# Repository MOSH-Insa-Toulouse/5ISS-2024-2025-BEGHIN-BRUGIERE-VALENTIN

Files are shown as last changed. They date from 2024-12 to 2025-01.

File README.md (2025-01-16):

# Gaz Sensor Application

## Introduction
The general objective of this project is to carry out the complete implementation of a gas sensor, from its manufacture, through its integration on a PCB, to its use in a concrete IoT application. This course gives us the opportunity to put our skills into practice at every stage in the design and development of a project. In particular, it covers the main phases such as hardware design, software design and product integration. Various digital tools were used, including KiCad for PCB design, LTSpice for analogue simulations and the Arduino platform for programming.

The application developed detects carbon monoxide and alerts you if critical thresholds are exceeded. Three LEDs indicate the alert levels: green for a safe level, orange for a high level and red for a dangerous level requiring evacuation. An OLED screen, connected via I2C, displays CO levels in real time to check the accuracy of the measurements. These measurements are then sent via a LoRa antenna and retrieved using the NodeRed software, which displays them.

This Git file and the following document contain the steps required to design our application, as well as the results obtained.

## LoRa Antenna
As mentioned above, the aim is to send the data measured by the sensor via a LoRa antenna. To do this, we used the open-source LoRaWAN Network Server ChirpStack, on which we created our application and generated its identifier and access key. Via this server, it is possible to connect to the GEI's main LoRa antenna and view the data stream sent to it.

On the programming side, we used the LoRa RN2483. This module has the advantage of communicating via the UART, so it was easy to connect it to the Arduino and have it send and receive data. We then had to reset and configure the RN2483 microchip according to the identifiers created on ChirpStack. Once this was done, we launched the connection tests and were able to check that our antenna was indeed connected to the main antenna via ChirpStack.

## Components Integration
### OLED Screen
As already mentioned, the OLED screen displays the carbon monoxide level measured by the sensor. The display is of the SSD1306 type and communicates via the I2C bus. We were therefore able to integrate it easily into our system, in particular by using adafruit libraries. By configuring the screen display, i.e. the size, colour and position of the text, we were able to display our first tests on the screen. We also used this screen as a test indicator to check the veracity and accuracy of the measurements taken by the sensor.
### Gaz Sensor
Adding the gas sensor to the application was not so easy. We had trouble understanding how the sensor worked and how to retrieve the measurements. However, after a bit of research we managed to get it to work properly.

This sensor detects the presence of carbon monoxide by a variation in resistance. First of all, the sensor has to be allowed to heat up in order to obtain values in line with reality, and then to adapt to its environment. The resistance value is recovered via a serial link and processed to obtain a usable level in ppm. We were then able to display on the screen the measurements taken in real time by the sensor.
### LEDs
To implement a visual alert, we decided to use three different coloured LEDs to symbolise our alert levels. The first level, green, means that the level of CO measured by the sensor is not toxic. The second, orange, symbolises that the quantity of gas is high and that exposure for too long can cause headaches. Finally, the red alert level lights up when the level of monoxide is above the safety threshold. Time to leave the room. We found the three thresholds in the literature on the websites of health bodies to reflect reality. The LEDs were switched on via a condition loop when the sensor measurements were retrieved.

## Node-RED Application
After that, we implemented Node-RED to visualise the data collected by the sensor. The idea was for the sensor readings transmitted via the LoRa antenna and processed by Chirpstack to be retrieved by Node-RED and displayed using its dashboard functionality. Using the MQTT protocol, we subscribed Node-RED to a Chirpstack topic in which it published the sensor measurements. This enabled us to retrieve the data transmitted on the LoRa network. The values were then displayed by creating a simple but powerful interface for viewing the gas sensor data in real time. 

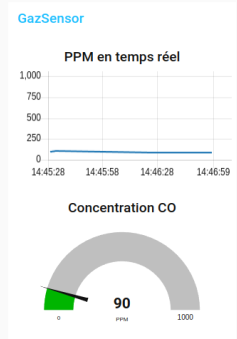
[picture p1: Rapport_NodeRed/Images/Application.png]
Node-Red Dashboard Vizualisation Node-Red Dashboard Vizualisation


For more information, read the Node-RED report [here](Rapport_NodeRed).

## The electrical circuit
Here is the complete electrical diagram of our system. It consists of the Arduino UNO shield, the three LEDs, the gas sensor, the OLED screen and an amplifier.

Electrical Circuit

The gas sensor produced has a very high resistance which varies according to the type and presence of gas. Its resistance is of the order of gigohms, which implies an extremely low current of the order of nanoampere (nA) flowing to the ADC. Using an Arduino with a 10-bit ADC requires the signal leaving the gas sensor to be amplified. We therefore designed an amplification circuit based on an operational amplifier and simulated it using LTSpice. To find out more, read the LT-Spice report [here](Rapport_LTSpice).

Amplifier

## PCB Design
The PCB was designed using KiCad software. Starting with the previous electrical circuit, the components had to be placed on the Arduino UNO shield and then routed. This was a complex process because we had a lot of components that were quite imposing in terms of space, which did not make placement easy. The final aim was, instead of using a breadboard, to have all the components needed for our application on a single board. The OLED screen and the connectors for the LoRa module have been placed on the other side of the shield so that they can be accessed. Here is the final PCB for our project.

PCB Design

Below, there is a 3D view of the PCB after conception.

-- Front view:

3D view front

--Back view:

3D view back

## Conclusion
The next stage of our project is to print the PCB and then solder the components. Finally, we will have to test our application by uploading our code onto the board. 

The overall objective of this module is to carry out the complete implementation of a gas sensor, from its manufacture, through its integration on a PCB, to its use in a concrete IoT application. This course thus gives us the opportunity to put our skills into practice at every stage of the design and development of a project. In particular, it covers the main phases such as hardware design, software design and product integration. 

In terms of energy consumption, we should look at the consumption of each component. If it is too high, we will have to switch to other components that consume less energy.

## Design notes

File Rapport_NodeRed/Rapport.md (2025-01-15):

# Node-RED in the Gas Sensor Monitoring Project

## Introduction

As part of our project, we implemented Node-RED to visualize data collected by a gas sensor. The sensor readings, transmitted via LoRa and processed by Chirpstack, were retrieved in Node-RED and displayed using its dashboard capabilities. This document outlines how we configured Node-RED for real-time data visualization.

---

## Role of Node-RED in Our Project

In our project, we used Node-RED for the visualization of gas sensor data. Its role was focused on:

1. **Data Retrieval**: Using an MQTT node, Node-RED subscribed to a Chirpstack topic to receive the sensor data transmitted over the LoRa network.
2. **Data Visualization**: The `node-red-dashboard` package allowed us to create a user interface for real-time monitoring of the gas concentration, specifically CO levels.

---

## Configuration of Node-RED for Data Visualization

To integrate Node-RED into our workflow, we followed the steps below:

### 1. Connecting to Chirpstack via MQTT
We used the `mqtt in` node to subscribe to the topic where Chirpstack published the gas sensor data. The node was configured with the following:
- The broker URL and port of Chirpstack.
- The correct topic for sensor data.
- Authentication details where required.

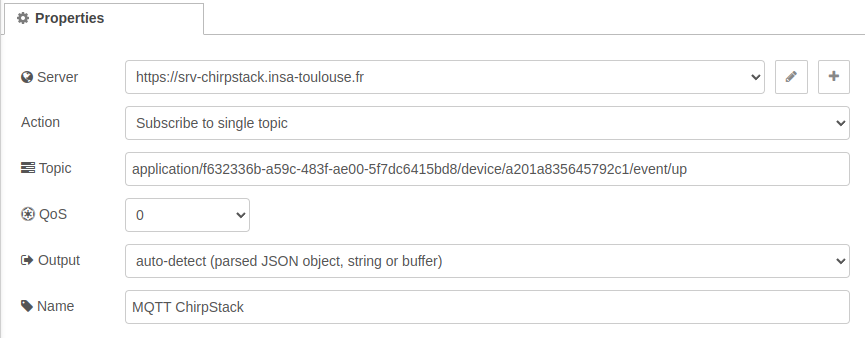
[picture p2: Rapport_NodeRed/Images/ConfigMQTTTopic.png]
Configuration Topic Broker MQTT

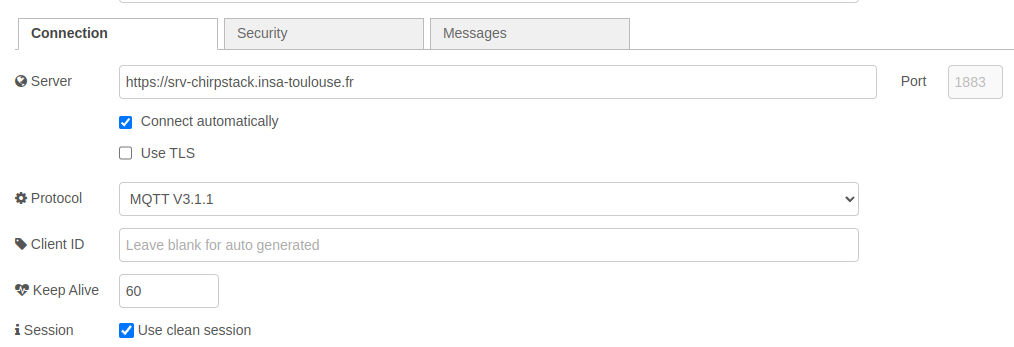
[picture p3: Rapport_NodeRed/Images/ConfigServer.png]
Configuration Server MQTT


### 2. Parsing the Data
The raw payload received from the MQTT node was in JSON format. We processed this data as follows:
- A `JSON` node was used to parse the payload into a structured format for easy handling.
- Function nodes were added to extract specific details such as gas concentration values and to reformat the data for better compatibility with dashboard widgets.

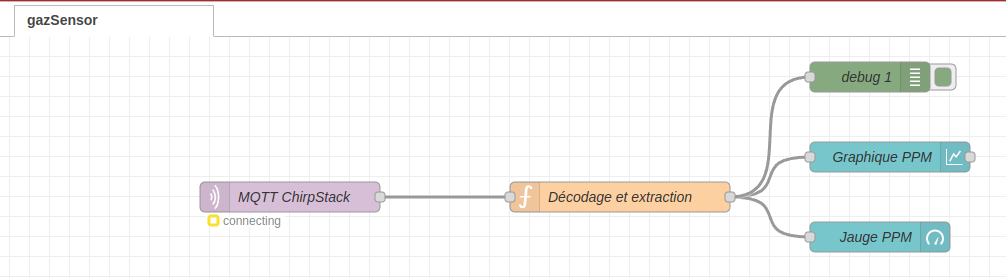
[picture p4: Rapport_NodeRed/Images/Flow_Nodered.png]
Node-Red Flow


### 3. Dashboard Configuration
For the visualization, we installed and configured the `node-red-dashboard` package:
- **Gauges** were used to display the current gas concentration levels.
- **Charts** plotted historical trends of gas readings over time.

Node-Red Dashboard Vizualisation Node-Red Dashboard Vizualisation

---

## Node-RED Flow Overview

Our Node-RED flow consisted of the following key components:

1. **Input Node**:
   - `mqtt in`: Subscribed to the Chirpstack topic for gas sensor data.
2. **Processing Node**:
   - `json`: Converted the raw payload into structured data.
3. **Visualization Nodes**:
   - `ui_gauge`: Displayed the current gas concentration level.
   - `ui_chart`: Graphed the real-time trends of gas readings.
   - `ui_text`: Added labels and contextual information.

*Image suggestion*: Provide a screenshot of the complete flow diagram from Node-RED to help visualize the workflow.

---

## Conclusion

Through Node-RED, we successfully created a simple yet powerful interface for visualizing gas sensor data in real time. The combination of MQTT integration and interactive dashboard widgets enabled us to effectively monitor CO levels transmitted via the LoRa network. This experience highlighted Node-RED’s suitability for rapid prototyping and student projects like ours, where simplicity and efficiency are key.

---

*Image suggestion*: Include a final screenshot of the dashboard showing live sensor data to showcase the outcome of the project.

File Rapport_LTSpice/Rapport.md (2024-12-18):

# Amplification Circuit for Gas Sensor with LTSpice Simulation

## Overview

The gas sensor made during the AIME week internship has an extremely high resistance that varies depending on the type and presence of gas. Its resistance is on the order of **gigohms**, resulting in an extremely low current in the **nanoampere (nA)** range flowing to the ADC. Using an Arduino with a 10-bit ADC necessitates amplifying the signal exiting the gas sensor. We designed an amplifier circuit based on an operational amplifier and simulated it using LTSpice.

Amplifying the signal allows us to avoid the need for expensive equipment like a €15,000 multimeter to measure the high resistance.

---

## Amplifying the Signal from the Sensor

### LTSpice Simulation

The amplifier uses **three different filters**, each with its own cutoff frequency. These filters are essential for shaping the signal and reducing noise. To accurately simulate the gas sensor's behavior, we created a custom sensor component in LTSpice that mimics its high resistance and response to gases.

### Circuit for Simulating the Sensor

Below is the LTSpice circuit used to simulate the gas sensor:

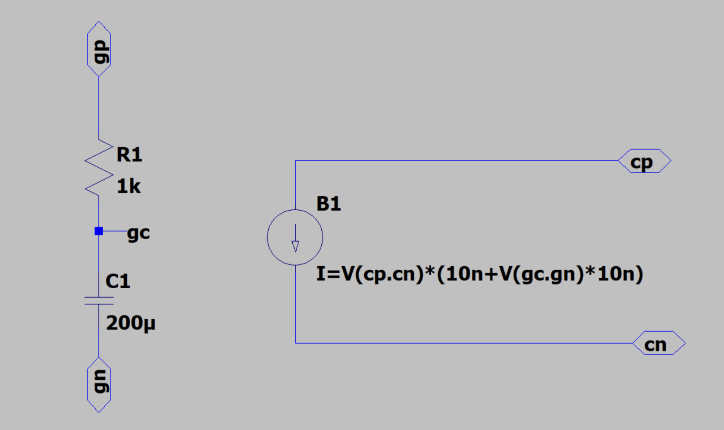
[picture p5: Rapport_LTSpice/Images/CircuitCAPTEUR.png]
Sensor Simulation Circuit


### LTSpice Circuit of the Amplifier

Below is the LTSpice circuit, integrating the gas sensor and filters:  
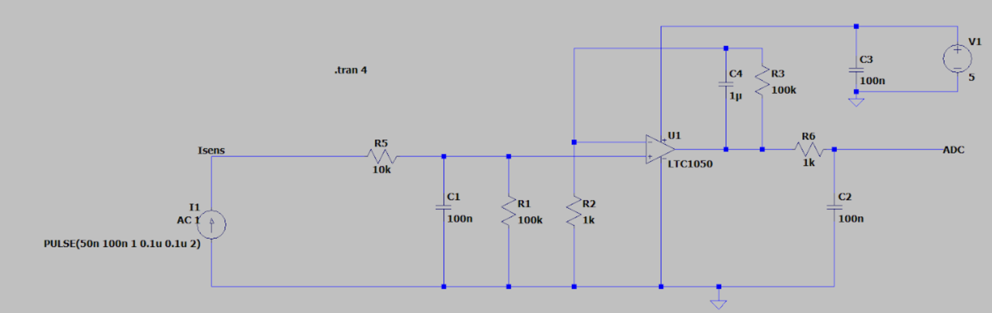
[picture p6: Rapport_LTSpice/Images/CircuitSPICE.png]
Sensor Simulation Circuit


---

## Verification of Nominal Functionality of the Amplifier

### Transient Response

Below is the LTSpice transient simulation for the input and output:

#### Input Transient Simulation:
- Input: PULSE of current, from **50 nA** to **100 nA**.
- Output observed: **5 mV** to **10 mV**, due to the **100 kΩ shunt resistance**.

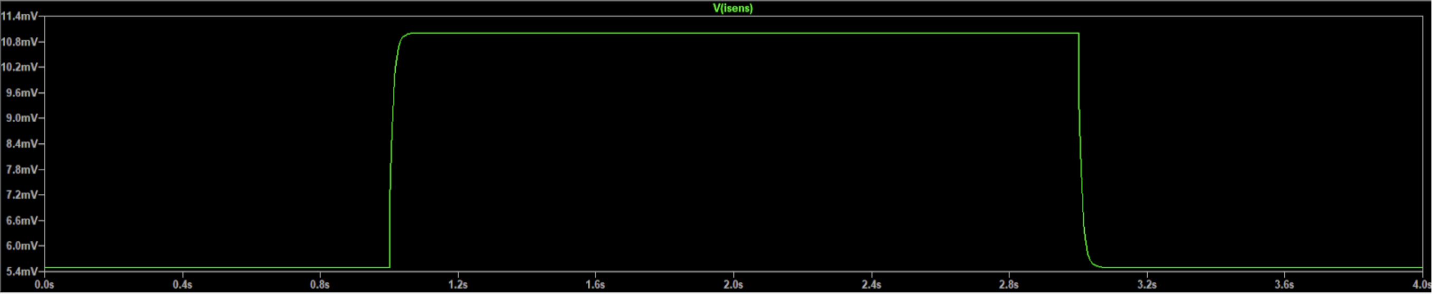
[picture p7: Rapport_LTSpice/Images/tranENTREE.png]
Transient Input


#### Output Transient Simulation:
- Voltage at the ADC is amplified by a factor of **101** (gain of the Amplificator = $1+\frac{100\text{k}}{1\text{k}}$).

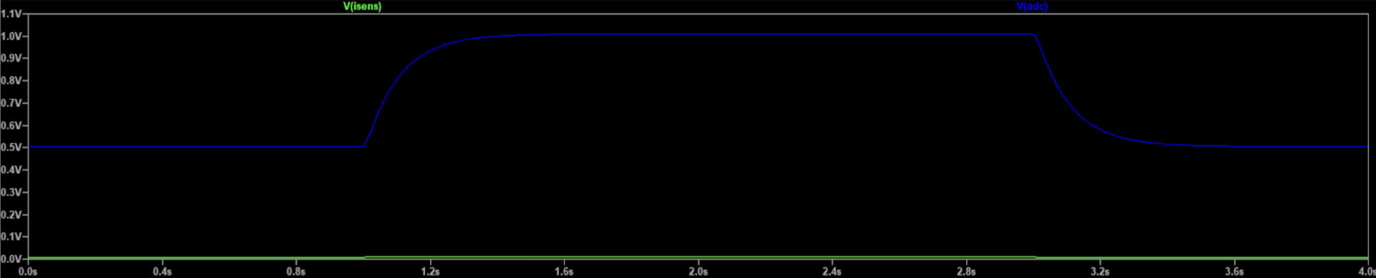
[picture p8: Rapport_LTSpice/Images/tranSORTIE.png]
Transient Output


The behaviour of our Amplifier is therefore correct, and we can go through the frequency analysis.

---

## Frequency Analysis

### Bode Diagram

The Bode diagram below shows the frequency response of the amplifier circuit:

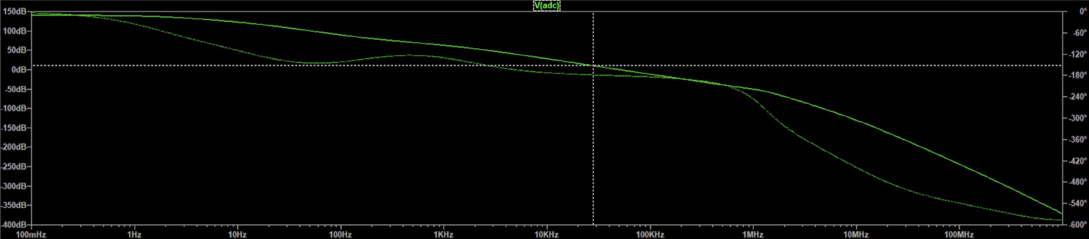
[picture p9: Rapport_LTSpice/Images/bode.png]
Bode Diagram Bode Diagram of Amplifier Circuit


The observed gain is **140 dB**, consistent with theoretical expectations.
Indeed, the transfer function is given by:

$H = \frac{V_{\text{out}}}{I_{\text{in}}}$

Where $V_{\text{out}} = 0.5 \text{V}$, $I_{\text{in}} = 50 \text{nA}$.  
Substituting into the formula, we get:

$H = \frac{0.5}{50 \times 10^{-9}} = 10^7$

On the other hand, we have 
$140 \text{dB}=10^{\frac{140}{20}} = 10^7$.
 
The Bode diagram results are coherent with the input-output data and confirm the amplifier's performance.

---

## Filter Design and Characterizing the Amplification

### Cutoff Frequencies and Attenuation

Below are the cutoff frequencies for each filter. They have been measured in LTSpice:

| Filter | Cutoff Frequency |
|---|---|
| 1 | $15$ Hz |
| 2 | $1.6$ Hz |
| 3 | $1.55$ kHz |

The filters have the following purposes:
1. **First Filter (C1, R1, R5):** Filters out noise originating from the gas sensor itself.
2. **Second Filter (C4, R3):** Reduces the **50 Hz** noise from the power grid.
3. **Third Filter (C2, R6):** Acts as an **anti-aliasing filter**, preventing signal distortion during digitization.

---

## Analysis of Noise and Filtering

### Frequency Analysis and Noise Reduction

FFT analysis of the ADC voltage demonstrates the effectiveness of the filters in reducing noise:
- **50 Hz Noise:** Clearly attenuated by the second filter (C4, R3).
- Increasing the second filter's capacitance reduces the 50 Hz noise further. However, excessive capacitance can distort the signal.

Fast Fourier Transform with the original filter:
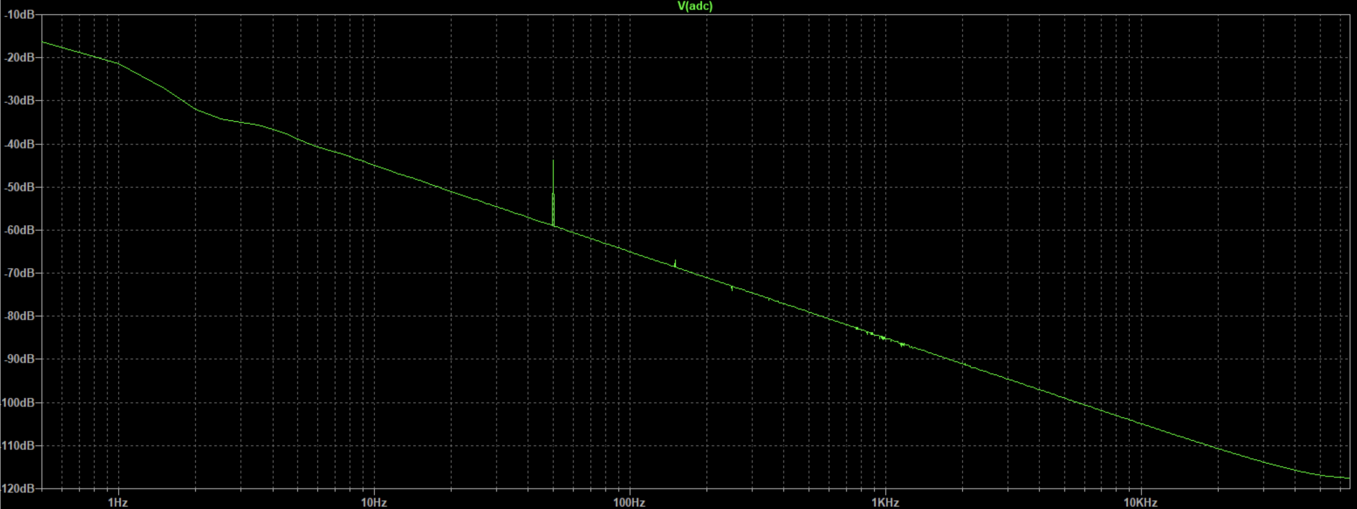
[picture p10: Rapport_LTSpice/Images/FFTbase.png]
FFT Bode Diagram of Amplifier Circuit


Fast Fourier Transform when increasing the capacitor too much:
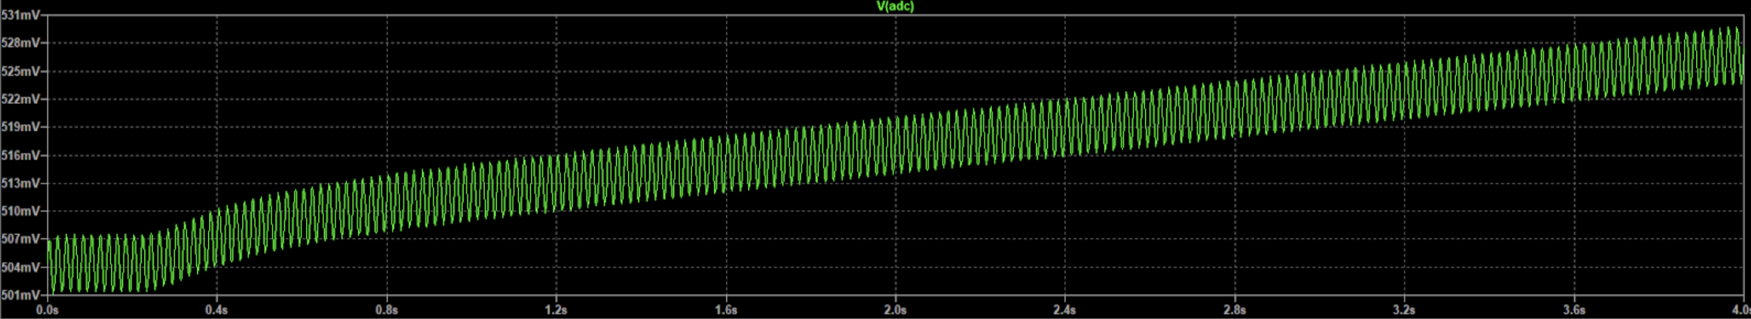
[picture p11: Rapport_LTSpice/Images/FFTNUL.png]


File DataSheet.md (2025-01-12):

# DataSheet of the gaz sensor

*This document presents the datasheet of the gaz sensor based on tungsten trioxide nanoparticles, manufactured at AIME.*

sensor 

**Main Features**             
  - Small size
  - Low cost                 
  - Detection of Ethanol ($C_2H_6O$)                              
  - Short response time
  - Integrated Temperature sensor

## Sensor Description
This gas sensor is designed to identify the presence of $C_2H_6O$ in the atmosphere. It functions as a passive component that detects gas presence through variations in its internal resistance. The incorporation of tungsten trioxide nanoparticles alters the conductivity of the aluminum interdigitated combs based on the gas composition in contact with the sensor. An internal heater allows the sensor to reach temperatures of up to 250°C, enhancing the sensitivity of the nanoparticles and minimizing interference from ambient humidity. Additionally, the sensor features an aluminum resistor to monitor its temperature, enabling improved control and the potential for temperature autoregulation.

## Pin Description
bottom_view 

| Pin Number | Usage |
|---|---|
| 1/6  |  Temperature sensor (Aluminium resistor) |
| 2/4  | Gas sensor ($WO_3$ nanoparticles integrated on aluminium interdigital combs) |
| 3/8  |  Heater resistor (Polysilicon resistor) |
| 7/9  |  Gas sensor ($WO_3$ nanoparticles integrated on aluminium interdigital combs) |
| 5/10  |  Not connected |

## Specifications
|  | Specificities |
|---|---|
| Type  | Nanoparticle based sensor |
| Sensor  | Passive (power supply required) |
| Materials  | - Silicon<br>- N-doped poly-silicon (heater)<br>- Aluminum (temperature measurement)<br>- Nanoparticles of tungsten trioxide ($WO_3$) |
| Detectable gaz  | Ethanol ($C_2H_6O$) |
| Gas measurement |  Resistance |
| Temperature measurement |  Resistance |
|  Package  | 10-Lead TO-5 metal  |
|  Diameter | 9.5 mm |

## Standard Test Conditions
|  | Unit | Typical Values |
|---|---|---|
| Temperature | °C | 20±5 |
| Humidity | % | 60±5 |
| Air quality | % $N_2/O_2$ | 80/20 |

## Electrical characteristics

<table>
  <tr>
    <th rowspan="2"></th>
    <th rowspan="2">Unit</th>
    <th colspan="3">Value</th>
  </tr>
  <tr>
    <th>Min</th>
    <th>Typical</th>
    <th>Max</th>
  </tr>
  <tr>
    <td>Gas sensor resistance</td>
    <td>GΩ</td>
    <td>-</td>
    <td>20</td>
    <td>-</td>
  </tr>
  <tr>
    <td>Temperature sensor resistance</td>
    <td>Ω</td>
    <td>84</td>
    <td>107.53</td>
    <td>108</td>
  </tr>
  <tr>
    <td>Heater resistance</td>
    <td>Ω</td>
    <td>70</td>
    <td>96.15</td>
    <td>98</td>
  </tr>
  <tr>
    <td>Gas sensor voltage</td>
    <td>V</td>
    <td>-</td>
    <td>5</td>
    <td>-</td>
  </tr>
  <tr>
    <td>Temperature sensor voltage</td>
    <td>V</td>
    <td>0</td>
    <td>5</td>
    <td>10</td>
  </tr>
  <tr>
    <td>Heater voltage</td>
    <td>V</td>
    <td>0</td>
    <td>10</td>
    <td>15</td>
  </tr>
</table>

## Temperature sensor characteristics
grapheALUAIME
From this graph representing the evolution of the temperature resistor, we obtain that the resistance is approximately : 107.53 Ω.

## Heating resistor characteristics


From this graph representing the evolution of the heater resistor, we obtain that the resistance is approximately : 96.15 Ω.

## Gas sensor characteristics
The gas sensor characteristic is determined by measuring the resistance evolution in presence of ethanol. When the resistance drops, the amount of ethanol in the environment increases. The gap is proportionnal to the gas concetration. 
gaz

## Sensor Integration

gazsensor

Above, there is a typical application of the sensor in an analogic circuit. The gaz sensor is 
connected in series with a resistors and with a RC filter. This filter aims to attenuate high frequencies. The outcoming tension is amplified 
by a LTC1050 operational amplifier before being filtered by a low pass filter. The 
tension from the ADC1 label can be connected to a 5V ADC such as an Arduino’s. 
The temperature sensor at pin TempB is also used as a resistor in a dividing bridge and the 
tension can be gathered by the ADC2 label. 

## Dimensions
The gas sensor uses a 10-Lead TO-5 metal package with the following dimensions:

dim

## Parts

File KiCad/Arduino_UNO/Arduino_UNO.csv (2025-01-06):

Source: | C:\Users\leabe\Documents\5A\MOSH\Arduino_UNO\Arduino_UNO.kicad_sch
Date: | 06/01/2025 14:32:44
Tool: | Eeschema 7.0.8
Generator: | C:\Program Files\KiCad\7.0\bin\scripting\plugins/bom_csv_grouped_by_value_with_fp.py
Component Count: | 25
Ref | Qnty | Value | Cmp name | Footprint | Description | Vendor | DNP
C1, C2, C3 | 3 | 100n | C | Capacitor_THT:C_Disc_D5.1mm_W3.2mm_P5.00mm | Unpolarized capacitor
C4 | 1 | 1u | C | Capacitor_THT:C_Rect_L7.5mm_W6.5mm_P5.00mm | Unpolarized capacitor
D1 | 1 | LED_Verte | LED | LED_THT:LED_D3.0mm | Light emitting diode
D2 | 1 | LED_Jaune | LED | LED_THT:LED_D3.0mm | Light emitting diode
D3 | 1 | LED_Rouge | LED | LED_THT:LED_D3.0mm | Light emitting diode
J1 | 1 | Power | Conn_01x08_1 | Connector_PinSocket_2.54mm:PinSocket_1x08_P2.54mm_Vertical | Generic connector, single row, 01x08, script generated (kicad-library-utils/schlib/autogen/connector/)
J2 | 1 | Digital/PWM | Conn_01x10 | Connector_PinSocket_2.54mm:PinSocket_1x10_P2.54mm_Vertical | Generic connector, single row, 01x10, script generated (kicad-library-utils/schlib/autogen/connector/)
J3 | 1 | Analog | Conn_01x06 | Connector_PinSocket_2.54mm:PinSocket_1x06_P2.54mm_Vertical | Generic connector, single row, 01x06, script generated (kicad-library-utils/schlib/autogen/connector/)
J4 | 1 | Digital/PWM | Conn_01x08 | Connector_PinSocket_2.54mm:PinSocket_1x08_P2.54mm_Vertical | Generic connector, single row, 01x08, script generated (kicad-library-utils/schlib/autogen/connector/)
J5 | 1 | Connecteur LoRa | Conn_01x08_2 | Connector_PinSocket_2.54mm:PinSocket_1x08_P2.54mm_Vertical | Generic connector, single row, 01x08, script generated (kicad-library-utils/schlib/autogen/connector/)
R1, R3 | 2 | 100k | R | Resistor_THT:R_Axial_DIN0207_L6.3mm_D2.5mm_P10.16mm_Horizontal | Resistor
R2, R6 | 2 | 1k | R | Resistor_THT:R_Axial_DIN0207_L6.3mm_D2.5mm_P10.16mm_Horizontal | Resistor
R4 | 1 | 100 | R | Resistor_THT:R_Axial_DIN0207_L6.3mm_D2.5mm_P10.16mm_Horizontal | Resistor
R5, R7 | 2 | 10k | R | Resistor_THT:R_Axial_DIN0207_L6.3mm_D2.5mm_P10.16mm_Horizontal | Resistor
R8, R9, R10 | 3 | 220 | R | Resistor_THT:R_Axial_DIN0207_L6.3mm_D2.5mm_P10.16mm_Horizontal | Resistor
U1 | 1 | LTC1050ACN8_PBF | LTC1050ACN8_PBF | Package_DIP:DIP-8_W7.62mm
U2 | 1 | DM-OLED096-636 | DM-OLED096-636 | DM-OLED096-636:MODULE_DM-OLED096-636
U3 | 1 | Gaz_Sensor | Gaz_Sensor | Package_TO_SOT_THT:TO-5-10_Window

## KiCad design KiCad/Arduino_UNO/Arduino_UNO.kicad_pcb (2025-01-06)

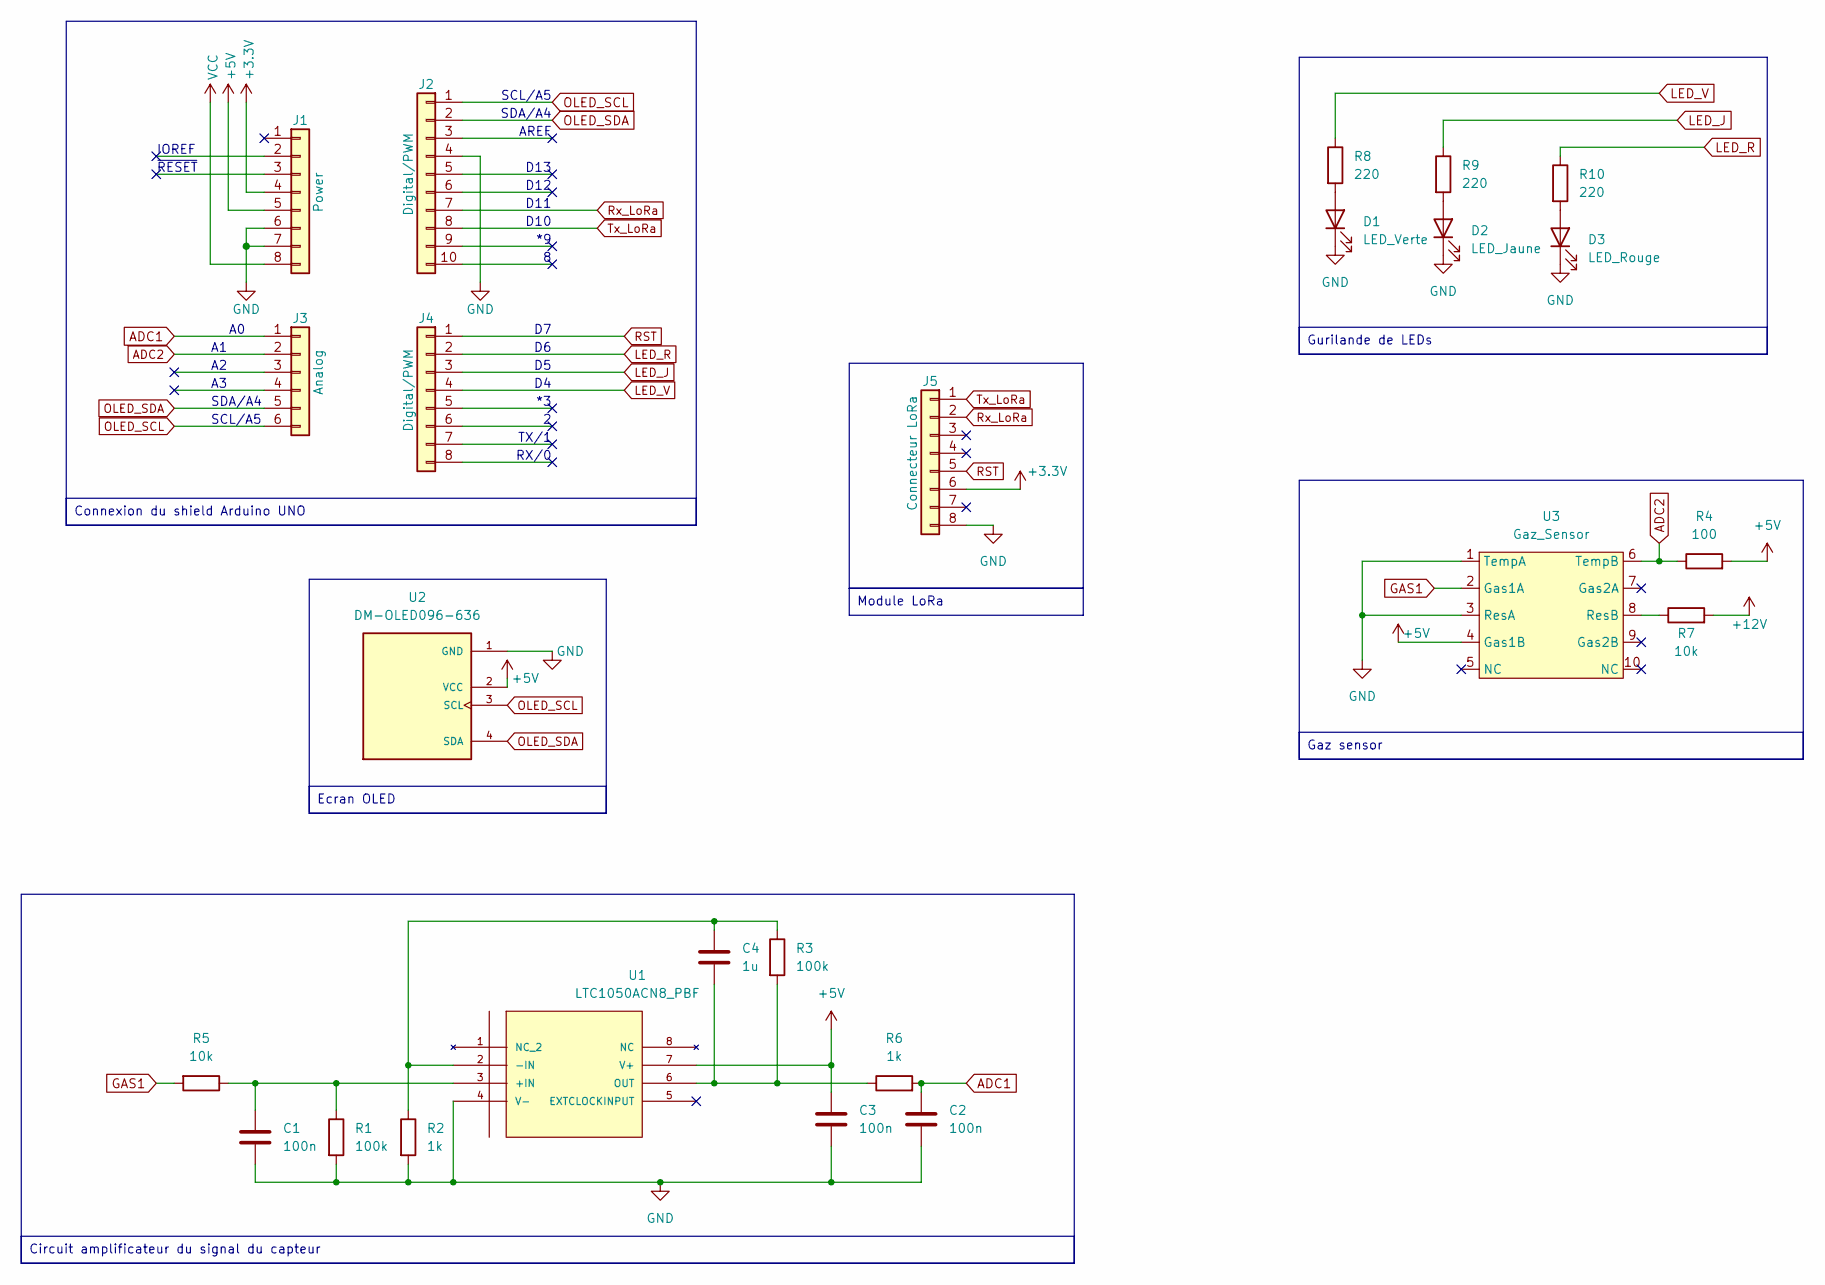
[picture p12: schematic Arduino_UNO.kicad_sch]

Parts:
C1, C2, C3: 100n; C_Disc_D5.1mm_W3.2mm_P5.00mm
C4: 1u; C_Rect_L7.5mm_W6.5mm_P5.00mm
D1: LED_Verte; LED_D3.0mm
D2: LED_Jaune; LED_D3.0mm
D3: LED_Rouge; LED_D3.0mm
J1: Power; PinSocket_1x08_P2.54mm_Vertical
J2: Digital/PWM; PinSocket_1x10_P2.54mm_Vertical
J3: Analog; PinSocket_1x06_P2.54mm_Vertical
J4: Digital/PWM; PinSocket_1x08_P2.54mm_Vertical
J5: Connecteur LoRa; PinSocket_1x08_P2.54mm_Vertical
R1, R3: 100k; R_Axial_DIN0207_L6.3mm_D2.5mm_P10.16mm_Horizontal
R2, R6: 1k; R_Axial_DIN0207_L6.3mm_D2.5mm_P10.16mm_Horizontal
R4: 100; R_Axial_DIN0207_L6.3mm_D2.5mm_P10.16mm_Horizontal
R5, R7: 10k; R_Axial_DIN0207_L6.3mm_D2.5mm_P10.16mm_Horizontal
R8, R9, R10: 220; R_Axial_DIN0207_L6.3mm_D2.5mm_P10.16mm_Horizontal
U1: LTC1050ACN8_PBF; DIP-8_W7.62mm; MANUFACTURER_PART_NUMBER ltc1050acn8
U2: DM-OLED096-636; MODULE_DM-OLED096-636; PARTREV 2018-09-10
U3: Gaz_Sensor; TO-5-10_Window

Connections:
+5V: C3.1, J1.5, R4.2, U1.7 (V+), U2.2 (VCC), U3.4 (Gas1B)
+12V: R7.2
ADC1: C2.1, J3.1, R6.2
ADC2: J3.2, R4.1, U3.6 (TempB)
GAS1: R5.2, U3.2 (Gas1A)
GND: C1.2, C2.2, C3.2, D1.1 (K), D2.1 (K), D3.1 (K), J1.6, J1.7, J2.4, J5.8, R1.2, R2.2, U1.4 (V-), U2.1 (GND), U3.1 (TempA), U3.3 (ResA)
LED_J: J4.3, R9.1
LED_R: J4.2, R10.1
LED_V: J4.4, R8.1
unnamed: D1.2 (A), R8.2
unnamed: D2.2 (A), R9.2
unnamed: D3.2 (A), R10.2
unnamed: C1.1, R1.1, R5.1, U1.3 (+IN)
unnamed: C4.1, R2.1, R3.1, U1.2 (-IN)
unnamed: C4.2, R3.2, R6.1, U1.6 (OUT)
unnamed: R7.1, U3.8 (ResB)
OLED_SCL: J2.1, J3.6, U2.3 (SCL)
OLED_SDA: J2.2, J3.5, U2.4 (SDA)
RST: J4.1, J5.5
Rx_LoRa: J2.7, J5.2
Tx_LoRa: J2.8, J5.1
VCC: J1.8

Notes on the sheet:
Gaz sensor
Gurilande de LEDs
Connexion du shield Arduino UNO
Module LoRa
Circuit amplificateur du signal du capteur
Ecran OLED
AREF
SCL/A5
TX/1
D13
~{RESET}
D12
D10
SDA/A4
RX/0
IOREF
D11

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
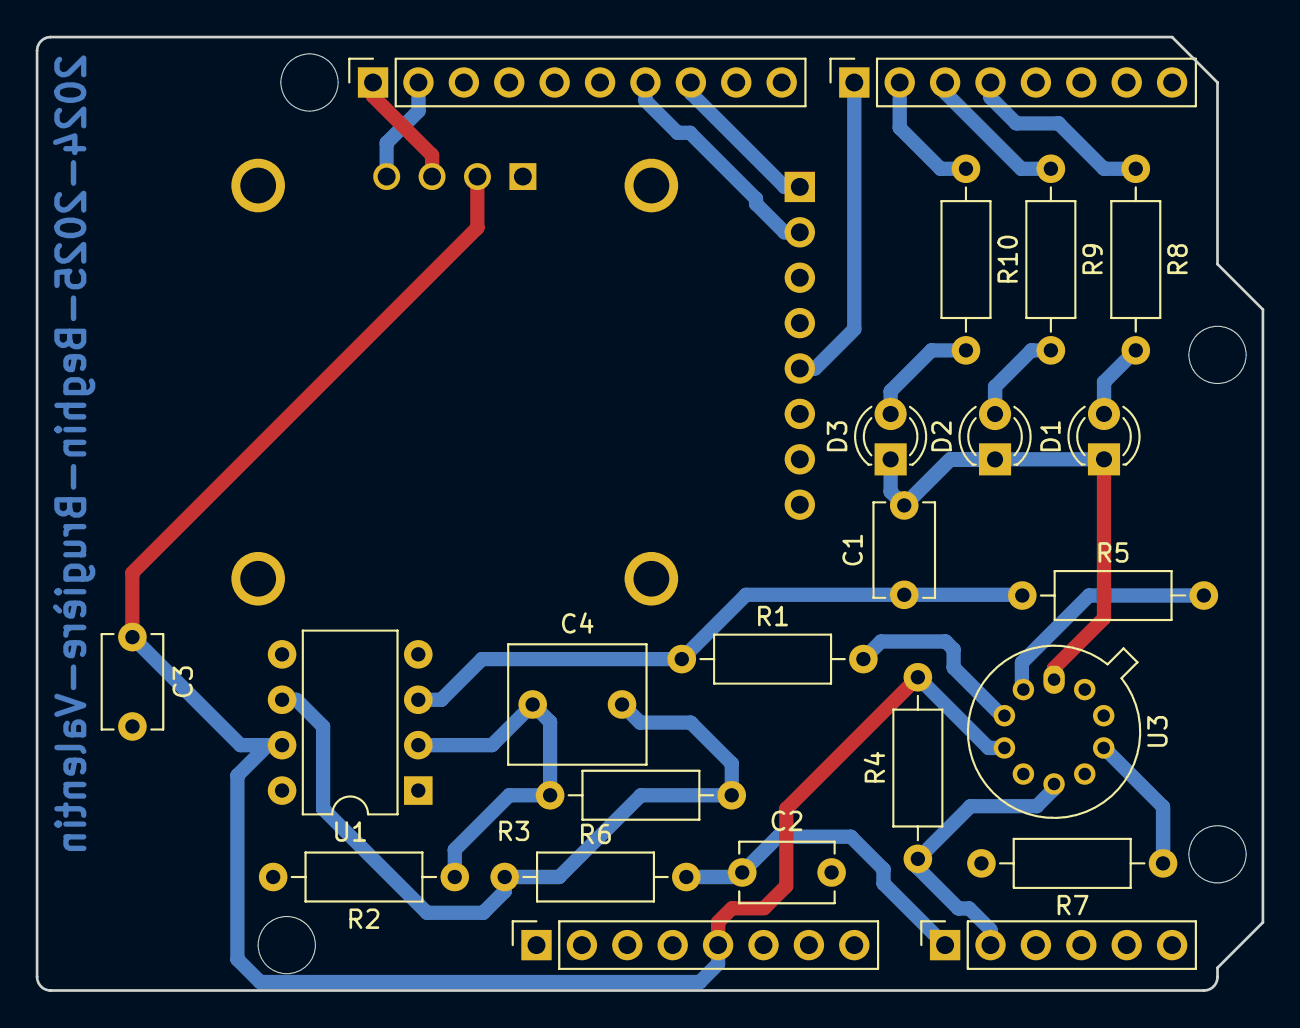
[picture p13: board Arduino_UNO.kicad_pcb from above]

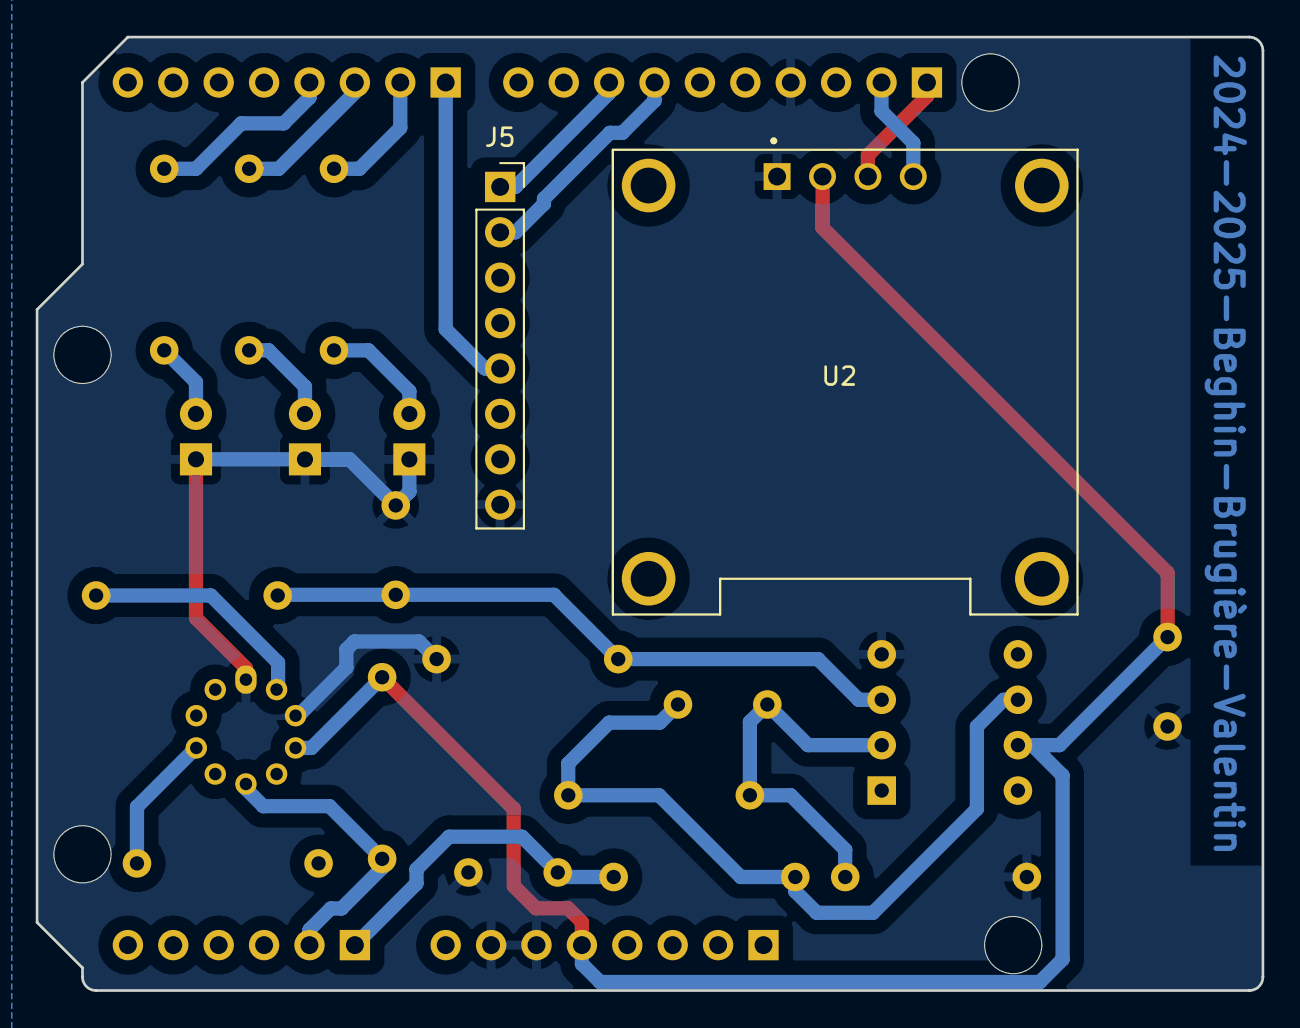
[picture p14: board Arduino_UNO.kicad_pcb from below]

Board: 2 copper layers, 68.6 x 53.3 mm, 29 parts (2 on the bottom side), 20 nets.

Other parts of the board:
MH1, MH2, MH3, MH4: MountingHole_3.2mm

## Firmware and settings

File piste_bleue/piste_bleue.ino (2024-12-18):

#include <Wire.h>
#include <Adafruit_GFX.h>
#include <Adafruit_SSD1306.h>
#include <SoftwareSerial.h>

SoftwareSerial loraSerial(10,11);

//----------------CONFIGURATION OLED----------------------//
// Taille de l'écran OLED (peut varier selon le modèle, ici 128x64)
#define SCREEN_WIDTH 128
#define SCREEN_HEIGHT 64

// Adresse I2C de l'écran OLED (par défaut : 0x3C)
#define OLED_ADDR 0x3C

// Déclaration de l'objet écran
Adafruit_SSD1306 display(SCREEN_WIDTH, SCREEN_HEIGHT, &Wire, -1);


//---------------CONFIGURATION CAPTEUR GAZ---------------//
const float RL_VALUE = 10.0; // Résistance de charge (en kΩ)
const float RO_CLEAN_AIR_FACTOR = 6.5; // Facteur Ro pour l'air propre (selon la datasheet)

float Ro = 10.0; // Résistance Ro initiale
float COCurve[3] = {2.3, 0.72, -0.34}; // Courbe pour le CO

void setup() {
  
  //---------------------Init OLED---------------------------------//
  Serial.println(F("Initialisation de l'OLED..."));
  // Initialisation de l'écran OLED
  Serial.begin(9600);
  if (!display.begin(SSD1306_SWITCHCAPVCC, OLED_ADDR)) {
    Serial.println(F("Échec de l'initialisation de l'écran OLED !"));
    while (true); // Bloque si l'écran ne démarre pas
  }
  // Efface l'écran
  display.clearDisplay();
  // Affichage du message "Joyeux Noël"
  display.setTextSize(2);         // Taille du texte (1 = petit, 2 = moyen, etc.)
  display.setTextColor(SSD1306_WHITE); // Couleur du texte (blanc sur fond noir)

  display.setCursor(10, 20);     // Position du texte (x=10, y=20)
  display.println(F(" Joyeux"));
  display.setCursor(10, 40);     // Position pour la ligne suivante
  display.println(F("  Noel!"));

  display.display(); // Met à jour l'affichage
  
  //----------------------Init LoRa-----------------------//
  loraSerial.begin(57600);
  pinMode(7,OUTPUT);

  Serial.println(F("Initialisation du RN2483..."));
  delay(1000);
  
  //Configuration
  digitalWrite(7,LOW);
  delay(1000);
  digitalWrite(7,HIGH);

  sendCommand(F("sys get ver"));
  delay(1000);
  sendCommand(F("mac set deveui a201a835645792c1"));
  delay(1000);
  sendCommand(F("mac get deveui"));
  delay(1000);
  sendCommand(F("mac set appeui a330a043fa4c27d3"));
  delay(1000);
  sendCommand(F("mac get appeui"));
  delay(1000);
  sendCommand(F("mac set appkey c2166795d078edc076cb9e9cc7143140"));
  delay(1000);

  //Connection
  sendCommand(F("mac join otaa"));

  //----------Init Gurlande---------------//
  pinMode(4,OUTPUT);
  pinMode(5,OUTPUT);
  pinMode(6,OUTPUT);

  //-----------Gas sensor------------------//
  Serial.println("Calibrating the sensor...");
  Ro = calibrateSensor();
  Serial.print("Calibration done! Ro = ");
  Serial.print(Ro);
  Serial.println(" kΩ");
}

void loop() {
  if (loraSerial.available()){
    String response = loraSerial.readStringUntil('\n');
    Serial.println("RN2483: " + response);
  }

  if (Serial.available()){
    String command = Serial.readStringUntil('\n');
    sendCommand(command);
  }
 
  float rs = readSensor(A0); // Lire Rs
  float ratio = rs / Ro; // Calculer Rs/Ro
  float ppm = getGasPPM(ratio, COCurve); // Convertir en ppm pour le CO
   
  display.clearDisplay();
  display.setCursor(10, 20);     // Position du texte (x=10, y=20)
  display.println(F(" CO:"));
  display.setCursor(10, 40);     // Position pour la ligne suivante
  display.println(ppm);

  display.display(); // Met à jour l'affichage

  //----------Guirlande------------//
  if (ppm<100){
    digitalWrite(4,HIGH);
    digitalWrite(5,LOW);
    digitalWrite(6,LOW);
  } else if ((ppm>100) && (ppm<200)){
    digitalWrite(5,HIGH);
    digitalWrite(4,LOW);
    digitalWrite(6,LOW);
  } else if (ppm>200){
    digitalWrite(6,HIGH);
    digitalWrite(4,LOW);
    digitalWrite(5,LOW);
  }


  // Envoi de la valeur ppm via LoRa
  sendPPMData(ppm);

  delay(1000);

}

void sendCommand(String command){
  while (loraSerial.available()){
    loraSerial.read();
  }
  loraSerial.println(command);
  Serial.println("Envoye : " + command);
  delay(1000);
  if (loraSerial.available()){
    String response = loraSerial.readStringUntil('\n');
    Serial.println("RN2483: " + response);
  }
}


// Fonction pour lire la résistance Rs
float readSensor(int pin) {
  int rawValue = analogRead(pin);
  float voltage = (rawValue / 1023.0) * 5.0; // Convertir en tension
  float rs = (5.0 - voltage) / voltage * RL_VALUE; // Calculer Rs
  return rs;
}

// Fonction de calibration
float calibrateSensor() {
  float rs = 0.0;
  for (int i = 0; i < 50; i++) {
    rs += readSensor(A0);
    delay(500);
  }
  rs = rs / 50.0; // Moyenne des valeurs lues
  return rs / RO_CLEAN_AIR_FACTOR; // Calculer Ro
}

// Fonction pour calculer le ppm
float getGasPPM(float ratio, float *curve) {
  return pow(10, ((log10(ratio) - curve[1]) / curve[2]) + curve[0]);
}

void sendPPMData(float ppm) {
  // Convertir le ppm en entier pour l'envoyer via LoRa (arrondi si nécessaire)
  int ppmInt = (int)ppm;
  
  // Convertir la valeur en hexadécimal
  String hexPayload = String(ppmInt, HEX);
  
  // Assurez-vous que la longueur de la chaîne est pair (Le module LoRa nécessite des octets pairs)
  if (hexPayload.length() % 2 != 0) {
    hexPayload = "0" + hexPayload; // Ajouter un zéro au début si la longueur est impaire
  }

  // Préparer la commande pour l'envoi via LoRa
  String command = "mac tx cnf 1 " + hexPayload;
  sendCommand(command); // Envoi de la commande avec le payload hexadécimal
}

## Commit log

2025-01-06 kicad files
    [Arduino_UNO-B_Cu.gbr, Arduino_UNO-B_Mask.gbr, Arduino_UNO-B_Silkscreen.gbr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]
2025-01-15 Rename Capture d’écran du 2025-01-15 08-20-30.png to Flow_Nodered
2025-01-15 Rename Capture d’écran du 2025-01-15 08-37-28.png to Application.png
2025-01-15 Rename Capture d’écran du 2025-01-15 08-21-01.png to DecodeurJSON.png
2025-01-15 Rename Capture d’écran du 2025-01-15 08-21-25.png to ConfigMQTTTopic.png
2025-01-15 Rename Capture d’écran du 2025-01-15 08-21-52.png to ConfigServer.png

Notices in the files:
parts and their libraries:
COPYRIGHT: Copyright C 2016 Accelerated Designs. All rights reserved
